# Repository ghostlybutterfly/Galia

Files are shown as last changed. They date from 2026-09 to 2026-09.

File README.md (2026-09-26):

# Galia
Modular split ergonomic keyboard system with each half consisting of a central motherboard and a hot-swappable key cluster daughterboard to allow for maximum flexibility.

### Motherboard
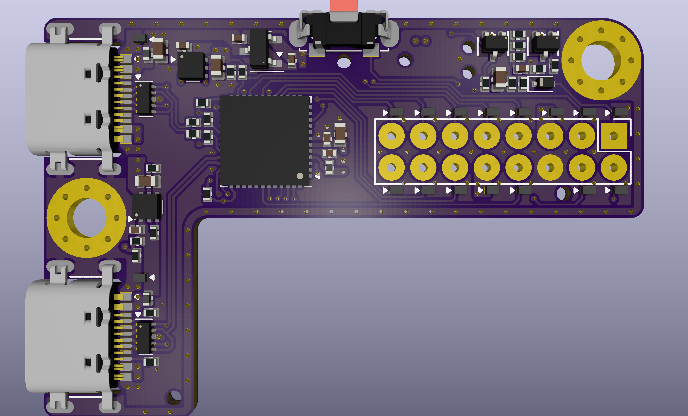
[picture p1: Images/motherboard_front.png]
Motherboard_Front

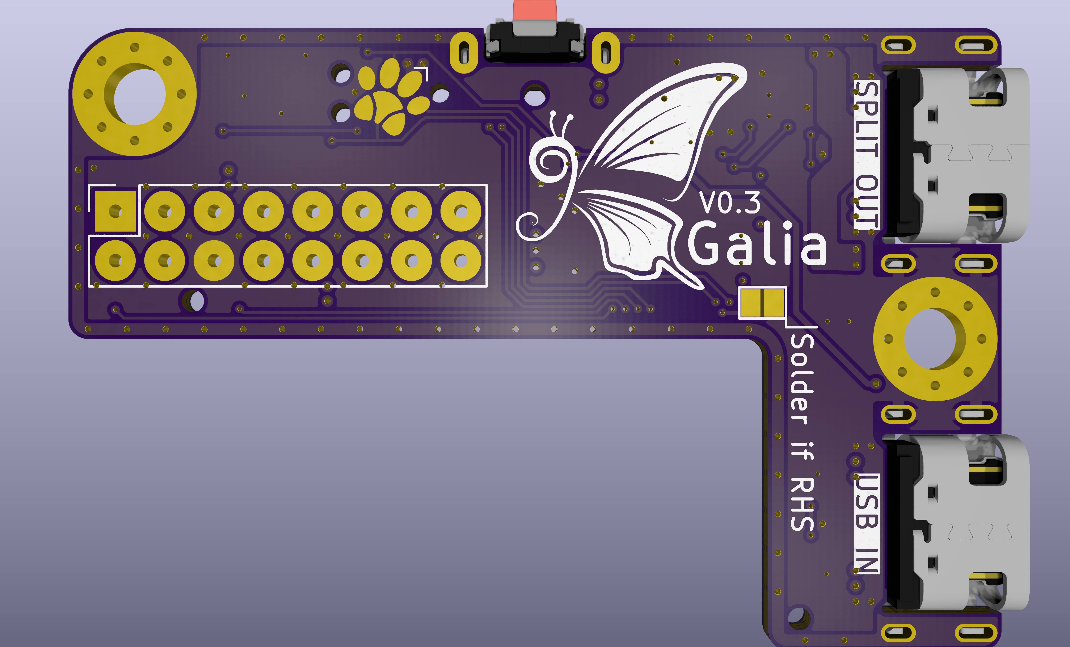
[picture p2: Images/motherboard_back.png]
Motherboard_Back

- Current version: V0.2.
- Schematic [here](https://kicanvas.org/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). 
- Board layout [here](https://kicanvas.org/?repo=https%3A%2F%2Fgithub.com%2Fghostlybutterfly%2FGalia%2Ftree%2FV0_dev%2FMotherboard).
### Daughterboard (Cantaloupe)
Current version: N/A (wip).

## Disclaimer
This keyboard is licensed under [CERN-OHL-S-2.0](https://cern-ohl.web.cern.ch/) and is compatible with both [QMK Firmware](https://qmk.fm/) and [ZMK Firmware](https://zmk.dev).

## Key Features
### Motherboard
* Fully reversible, compact (32.0x48.0mm), and designed to fit onto the top inner corner of a split keyboard.
* On-board STM32G0B1CCU7 processor.
* ESD-protected USB-C input port and USB-C split comms ports with ideal diode configuration for reverse current protection on VBUS input.
* Connects to daughterboard through fully ESD-protected 2.54mm pitch 02x08 pogo header in [VIK](https://github.com/sadekbaroudi/vik) breakout layout with three additional GPIO and reset button pin.
* 4-layer (signal/ground/power/signal) PCB, guard ring around PCB, and star ground connection point in between USB port shields to reduce EMI.
* VBUS input rail limited to ~500mA and 5V output rail limited to ~188mA through the use of TPS2553-1 current limiting switches with reverse voltage protection. VBUS requires power cycling to restart the device upon overcurrent, +5V can be power-cycled through firmware with EN pin controlled through firmware to reduce RGB LED quiescent current draw.
* 2x05 1.27mm Samtec IDC SWD header for debugging purposes or [Paw-Connect](https://github.com/LeoDJ/Paw-Connect) TC-2030NL header - both fit in the same space and are effectively interchangeable
* On-board button[Acheron](https://acheronproject.com/reset_article_1/reset_article_1/#52-substituting-the-jfet) single-button reset circuit.
* JLC basic assembly compatible as long as USB ports are not soldered on.

### Daughterboard (TBC)
* Matrix scan planned to be implemented through 74HC595 SIPO shift registers for low power draw and compatibility with ZMK interrupt functionality.
* Also compatible with charlieplex, duplex, and standard matrix layouts.
* WS2812 and AP102 (QMK only) LED support.
* Additional [VIK](https://github.com/sadekbaroudi/vik) header support if desired.
* USART1, USART3, and reset circuit pins routed to pogo pin header to allow for relocation of split comms receptacle and reset button on daughterboard.

## Pogo header pinout
| Function/description | Pin name | Row 1 | Row 2 | Pin name | Function/description |
| --- | --- | ----- | ----- | --- | --- |
| Active high, hold for 1.6s for DFU | N/A | RST | GPIO5 | B8 | SPI2 SCK/TIM4 CH3/I2C1 SCL |
| USART1 TX/SPI2 MISO/I2C1 SCL/TIM1 CH3 | B6 | GPIO3 | GPIO4 | B7 | USART1 RX/SPI2 MOSI/TIM4 CH2/I2C1 SDA |
| 200mA max draw across system | N/A | 3V3 | GND | N/A | N/A |
| I2C2 SDA | B4 | SDA | SCL | B3 | I2C2 SCL |
| SPI2 MOSI/TIM2 CH4 | B11 | RGB | 5V | N/A | 188mA max draw by daughterboard |
| USART3 TX/SPI2 MISO/ACD IN10 | B2 | GPIO1 | MOSI  | A7 | SPI1 MOSI |
| USART3 RX/TIM3 CH3/TIM1 CH2N/ADC IN8  | B0 | GPIO2 | CS | A4 | SPI1 NSS |
| SPI1 MISO | A6 | MISO  | SCK | A5 | SPI1 SCK |

## VIK keyboard certification card
| Category | Classification | Response |
| ---  | --- | --- |
| FPC connector | Required | 2.54mm pogo header |
| Breakout pins | Recommended | :heavy_check_mark: |
| Supplies: SPI | Strongly recommended | :heavy_check_mark: |
| Supplies: I2C | Strongly recommended | :heavy_check_mark: |
| I2C on main PCB | Discouraged | :x: |
| I2C pull ups | Informative | :x: |
| Supplies: RGB | Strongly recommended | :heavy_check_mark: |
| Supplies: Extra GPIO 1 | Required | Analog/Digital |
| Supplies: Extra GPIO 2 | Required | Analog/Digital |

## Changelog
* 2026/09/26: V0.3 motherboard update complete. Reduced size again, rerouted board and changed shape slightly. Removed one mounting hole and centred the other between the USB ports. Changed input fuse and external +5V output to TPS2553-1 latching power switch with reverse voltage/current protection. Removed AO3401 and LMV321 discrete reverse current protection at VBUS input. Reduced size of VBUS and VSPLIT ferrite bead and transistors in the Acheron reset circuit. Made Acheron reset circuit reach DFU faster. 
* 2026/09/21: V0.2 motherboard update complete. Significantly decreased size. GPIO3, GPIO4 and GPIO5 pins changed. Increased size of pogo pin header pads. Removed extra IO header. Replaced 2x03 2.54mm programming header and TC2030-NL with 2x05 1.27mm Samtec IDC header. Replaced reset switch with smaller Alps SKSNLP mid-mount switch. Added layer marker. Changed repository file structure.
* 2026/09/17: Fixed gap in guard rail.
* 2026/09/16: V0.1 motherboard initial commit.

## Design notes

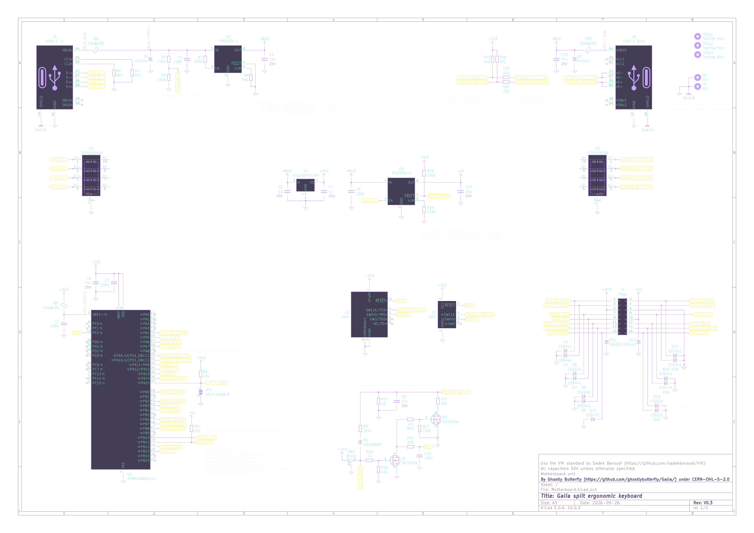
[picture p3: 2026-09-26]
Images/motherboard_schematic.png

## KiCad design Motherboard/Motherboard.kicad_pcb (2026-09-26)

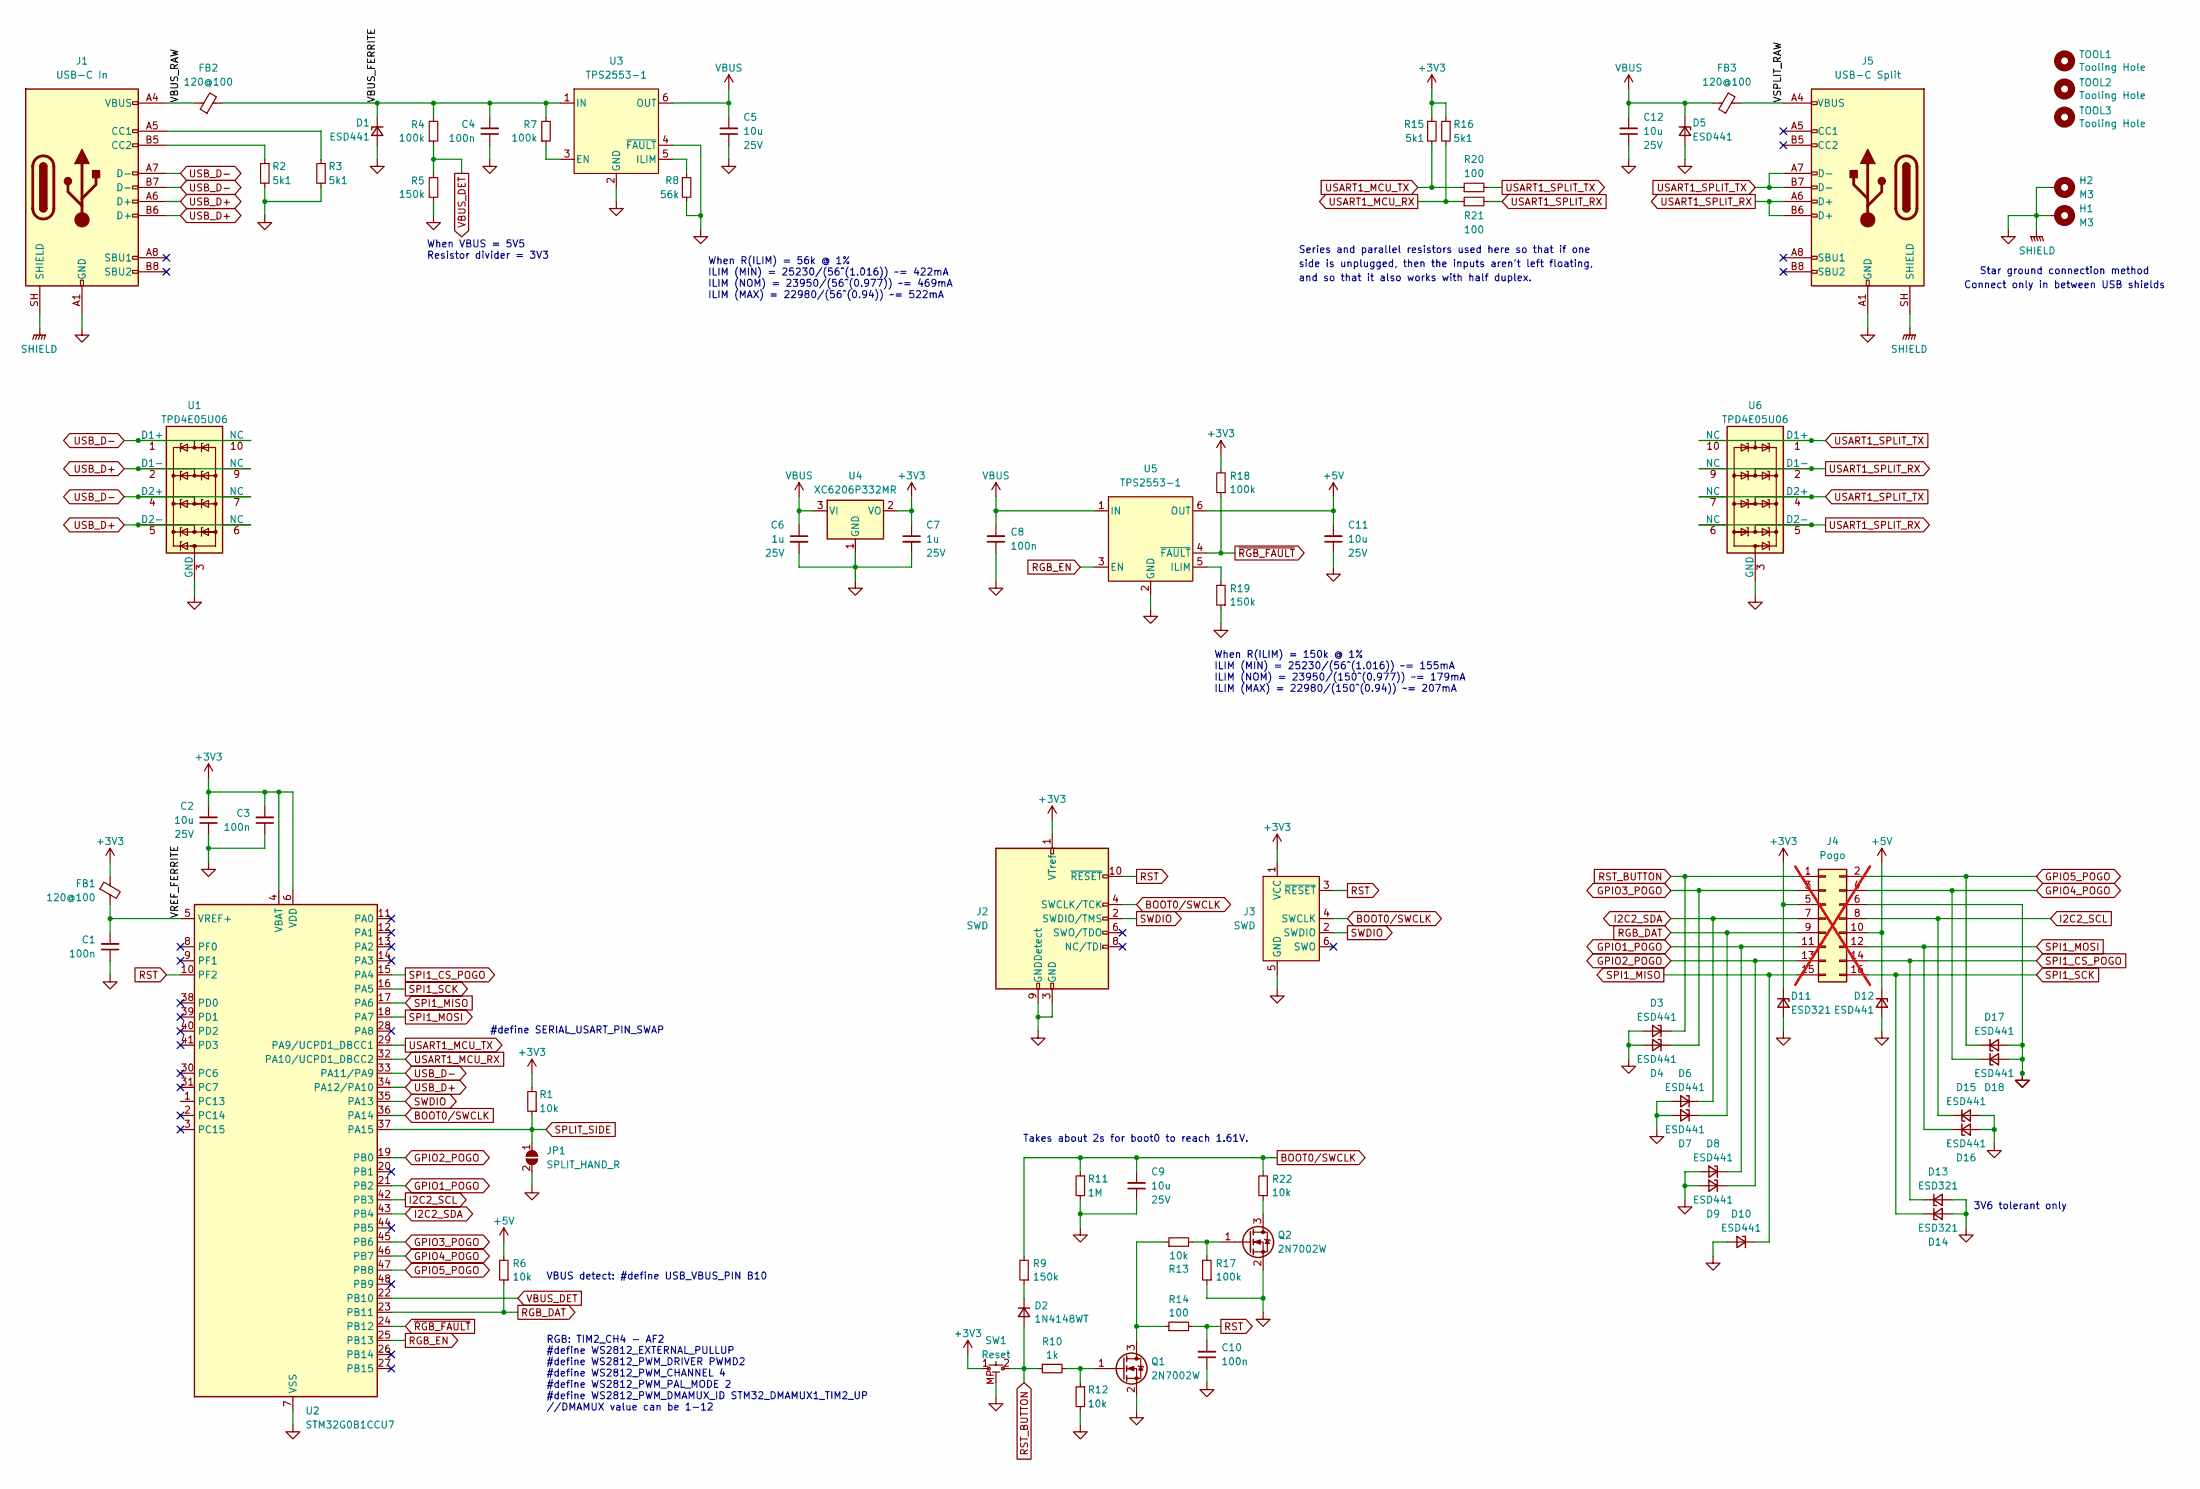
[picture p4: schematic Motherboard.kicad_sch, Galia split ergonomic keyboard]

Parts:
C1, C3, C4, C8, C10: 100n; C_0402_1005Metric; Rating 50V; MPN CL05B104KB54PNC; LCSC C307331
C2, C5, C9, C11, C12: 10u; C_0603_1608Metric; Rating 25V; MPN CL10A106MA8NRNC; LCSC C96446
C6, C7: 1u; C_0402_1005Metric; Rating 25V; MPN CL05A105KA5NQNC; LCSC C52923
D1, D3, D4, D5, D6, D7, D8, D9, D10, D12, D15, D16, D17, D18: ESD441; X1SON_0.6x1mm_P0.65mm_Texas_DPY0002A; MPN ESD441DPYR; LCSC C53161160
D2: 1N4148WT; D_SOD-523; MPN 1N4148WT; LCSC C7420320
D11, D13, D14: ESD321; X1SON_0.6x1mm_P0.65mm_Texas_DPY0002A; MPN ESD321DPYR; LCSC C2868952
FB1, FB2, FB3: 120@100; L_0402_1005Metric; MPN MPZ1005S121ET000; LCSC C275477
H1, H2: M3; MountingHole_3.2mm_M3_Pad_Via; MPN N/A; LCSC N/A
J1: USB-C In; USB_C_Receptacle_Molex_2169900001; MPN GT-USB-7014D; LCSC C2843969
J2: SWD; PinHeader_2x05_P1.27mm_Vertical_Samtec-FTSH-105-01-L-D-K; MPN FTSH-105-01-L-D-K; LCSC N/A
J3: SWD; Paw-Connect_RevB_TC2030-IDC-NL_2x03_P1.27mm_Vertical
J4: Pogo; PinHeader_2x08_2.54mm_MillMax_PogoTarget_419-10-216-00-0010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; MPN 419-10-214-00-001000; LCSC N/A; not fitted
J5: USB-C Split; USB_C_Receptacle_Molex_2169900001; MPN GT-USB-7014D; LCSC C2843969
JP1: SPLIT_HAND_R; SolderJumper-2_P1.2mm_Open_Pad1.0x1.4mm; MPN N/A; LCSC N/A
Q1, Q2: 2N7002W; SOT-323_SC-70-3; MPN 2N7002W; LCSC C7420322
R1, R6, R12, R13, R22: 10k; R_0402_1005Metric; MPN 0402WGF1002TCE; LCSC C25744
R2, R3, R15, R16: 5k1; R_0402_1005Metric; MPN 0402WGF5101TCE; LCSC C25905
R4, R7, R17, R18: 100k; R_0402_1005Metric; MPN 0402WGF1003TCE; LCSC C25741
R5, R9, R19: 150k; R_0402_1005Metric; MPN 0402WGF1503TCE; LCSC C25755
R8: 56k; R_0402_1005Metric; MPN 0402WGF5602TCE; LCSC C25796
R10: 1k; R_0402_1005Metric; MPN 0402WGF1001TCE; LCSC C11702
R11: 1M; R_0402_1005Metric; MPN 0402WGF1004TCE; LCSC C26083
R14, R20, R21: 100; R_0402_1005Metric; MPN 0402WGF1000TCE; LCSC C25076
SW1: Reset; SW_Alps_SKSNLM_SKSNLP; MPN SKSNLPE010; LCSC C53113391
TOOL1, TOOL2, TOOL3: Tooling Hole; MountingHole_JLC-Tooling; MPN N/A; LCSC N/A
U1, U6: TPD4E05U06; USON-10_2.5x1.0mm_P0.5mm; MPN TPD4E05U06QDQARQ1; LCSC C81353
U2: STM32G0B1CCU7; QFN-48-1EP_7x7mm_P0.5mm_EP5.6x5.6mm; MPN STM32G0B1CCU7; LCSC C29759424
U3, U5: TPS2553-1; WSON-6-1EP_2x2mm_P0.65mm_EP1x1.6mm
U4: XC6206P332MR; SOT-23-3; MPN XC6206P332MR-G; LCSC C5446

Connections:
+3V3: C2.2, C3.2, C7.1, D11.1 (K), FB1.1, J2.1 (VTref), J3.1 (VCC), J4.5, R1.2, R15.1, R16.1, R18.2, SW1.1 (A), U2.4 (VBAT), U2.6 (VDD), U4.2 (VO)
+5V: C11.2, D12.1 (K), J4.10, R6.2, U5.6 (OUT)
/VBUS_FERRITE: C4.2, D1.1 (K), FB2.2, R4.2, R7.2, U3.1 (IN)
/VBUS_RAW: FB2.1, J1.A4 (VBUS), J1.A9 (VBUS), J1.B4 (VBUS), J1.B9 (VBUS)
/VREF_FERRITE: C1.2, FB1.2, U2.5 (VREF+)
/VSPLIT_RAW: FB3.2, J5.A4 (VBUS), J5.A9 (VBUS), J5.B4 (VBUS), J5.B9 (VBUS)
BOOT0/SWCLK: C9.2, J2.4 (SWCLK/TCK), J3.4 (SWCLK), R9.2, R11.1, R22.2, U2.36 (PA14)
GND: C1.1, C2.1, C3.1, C4.1, C5.1, C6.2, C7.2, C8.1, C9.1, C10.1, C11.1, C12.1, D1.2 (A), D3.2 (A), D4.2 (A), D5.2 (A), D6.2 (A), D7.2 (A), D8.2 (A), D9.2 (A), D10.2 (A), D11.2 (A), D12.2 (A), D13.2 (A), D14.2 (A), D15.2 (A), D16.2 (A), D17.2 (A), D18.2 (A), H1.1 (1_1), H2.1 (1_1), J1.A1 (GND), J1.A12 (GND), J1.B1 (GND), J1.B12 (GND), J1.SH (SHIELD), J2.3 (GND), J2.5 (GND), J2.9 (GNDDetect), J3.5 (GND), J4.6, J5.A1 (GND), J5.A12 (GND), J5.B1 (GND), J5.B12 (GND), J5.SH (SHIELD), JP1.2 (B), Q1.2 (S), Q2.2 (S), R2.2, R3.2, R5.1, R8.2, R11.2, R12.2, R17.1, R19.1, SW1.MP (A), U1.3 (GND), U1.8 (GND), U2.7 (VSS), U2.49 (VSS), U3.2 (GND), U3.4 (~FAULT), U3.7 (EP), U4.1 (GND), U5.2 (GND), U5.7 (EP), U6.3 (GND), U6.8 (GND)
GPIO1_POGO: D8.1 (K), J4.11, U2.21 (PB2)
GPIO2_POGO: D9.1 (K), J4.13, U2.19 (PB0)
GPIO3_POGO: D4.1 (K), J4.3, U2.45 (PB6)
GPIO4_POGO: D18.1 (K), J4.4, U2.46 (PB7)
GPIO5_POGO: D17.1 (K), J4.2, U2.47 (PB8)
I2C2_SCL: D15.1 (K), J4.8, U2.42 (PB3)
I2C2_SDA: D6.1 (K), J4.7, U2.43 (PB4)
unnamed: D2.1 (K), R9.1
unnamed: J1.A5 (CC1), R3.1
unnamed: J1.B5 (CC2), R2.1
unnamed: Q1.3 (D), R13.1, R14.1
unnamed: Q1.1 (G), R10.2, R12.1
unnamed: Q2.3 (D), R22.1
unnamed: Q2.1 (G), R13.2, R17.2
unnamed: R7.1, U3.3 (EN)
unnamed: R8.1, U3.5 (ILIM)
unnamed: R19.2, U5.5 (ILIM)
RGB_DAT: D7.1 (K), J4.9, R6.1, U2.23 (PB11)
RGB_EN: U2.25 (PB13), U5.3 (EN)
RST: C10.2, J2.10 (~RESET), J3.3 (~RESET), R14.2, U2.10 (PF2)
RST_BUTTON: D2.2 (A), D3.1 (K), J4.1, R10.1, SW1.2 (B)
SPI1_CS_POGO: D13.1 (K), J4.14, U2.15 (PA4)
SPI1_MISO: D10.1 (K), J4.15, U2.17 (PA6)
SPI1_MOSI: D16.1 (K), J4.12, U2.18 (PA7)
SPI1_SCK: D14.1 (K), J4.16, U2.16 (PA5)
SPLIT_SIDE: JP1.1 (A), R1.1, U2.37 (PA15)
SWDIO: J2.2 (SWDIO/TMS), J3.2 (SWDIO), U2.35 (PA13)
USART1_MCU_RX: R16.2, R21.1, U2.32 (PA10/UCPD1_DBCC2)
USART1_MCU_TX: R15.2, R20.1, U2.29 (PA9/UCPD1_DBCC1)
USART1_SPLIT_RX: J5.A6 (D+), J5.B6 (D+), R21.2, U6.2 (D1-), U6.5 (D2-), U6.6 (NC), U6.9 (NC)
USART1_SPLIT_TX: J5.A7 (D-), J5.B7 (D-), R20.2, U6.1 (D1+), U6.4 (D2+), U6.7 (NC), U6.10 (NC)
USB_D+: J1.A6 (D+), J1.B6 (D+), U1.2 (D1-), U1.5 (D2-), U1.6 (NC), U1.9 (NC), U2.34 (PA12/PA10)
USB_D-: J1.A7 (D-), J1.B7 (D-), U1.1 (D1+), U1.4 (D2+), U1.7 (NC), U1.10 (NC), U2.33 (PA11/PA9)
VBUS: C5.2, C6.1, C8.2, C12.2, D5.1 (K), FB3.1, U3.6 (OUT), U4.3 (VI), U5.1 (IN)
VBUS_DET: R4.1, R5.2, U2.22 (PB10)
~RGB_FAULT: R18.1, U2.24 (PB12), U5.4 (~FAULT)

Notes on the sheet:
3V6 tolerant only
#define WS2812_EXTERNAL_PULLUP #define WS2812_PWM_DRIVER PWMD2 #define WS2812_PWM_CHANNEL 4 #define WS2812_PWM_PAL_MODE 2 #define WS2812_PWM_DMAMUX_ID STM32_DMAMUX1_TIM2_UP //DMAMUX value can be 1-12
When R(ILIM) = 56k @ 1% ILIM (MIN) = 25230/(56^(1.016)) ~= 422mA ILIM (NOM) = 23950/(56^(0.977)) ~= 469mA ILIM (MAX) = 22980/(56^(0.94)) ~= 522mA
Takes about 2s for boot0 to reach 1.61V.
RGB: TIM2_CH4 - AF2
Series and parallel resistors used here so that if one
VBUS detect: #define USB_VBUS_PIN B10
side is unplugged, then the inputs aren't left floating,
and so that it also works with half duplex.
When VBUS = 5V5 Resistor divider = 3V3
Connect only in between USB shields
#define SERIAL_USART_PIN_SWAP
When R(ILIM) = 150k @ 1% ILIM (MIN) = 25230/(56^(1.016)) ~= 155mA ILIM (NOM) = 23950/(150^(0.977)) ~= 179mA ILIM (MAX) = 22980/(150^(0.94)) ~= 207mA
Star ground connection method

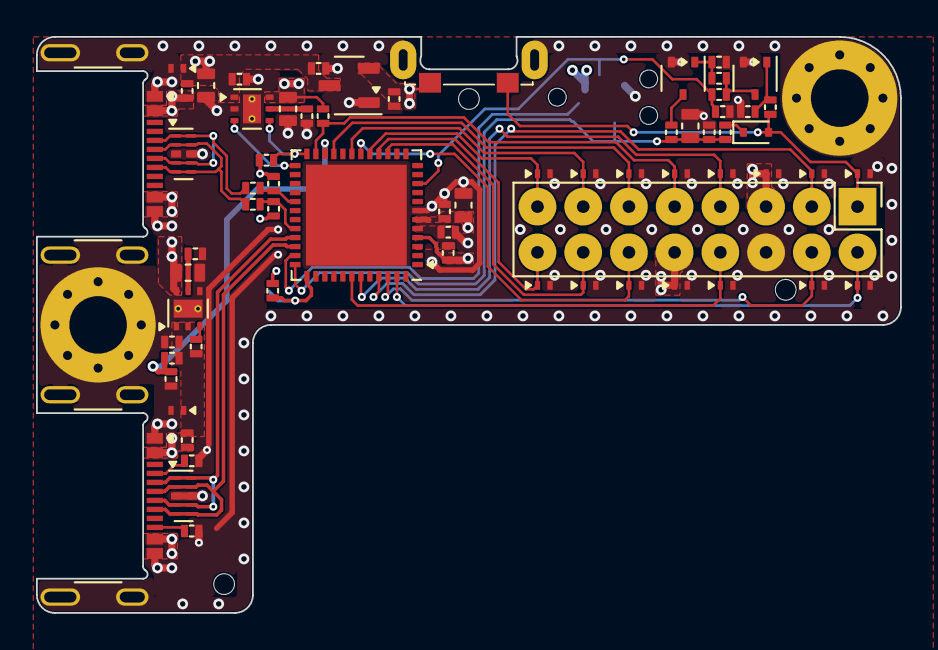
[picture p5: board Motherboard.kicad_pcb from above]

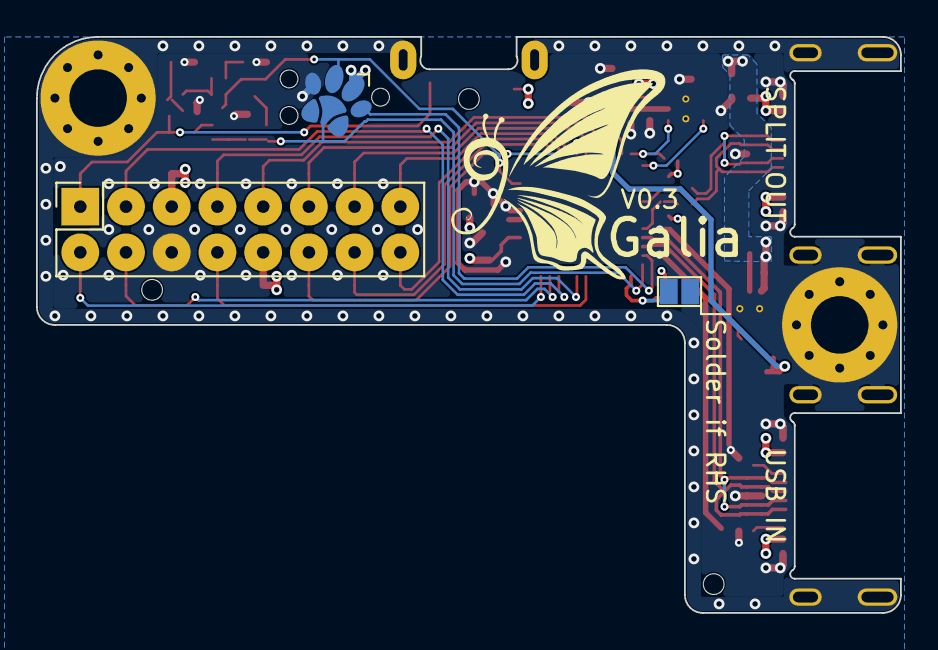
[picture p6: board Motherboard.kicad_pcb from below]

Board: 4 copper layers, 48.0 x 32.0 mm, 74 parts (3 on the bottom side), 44 nets.

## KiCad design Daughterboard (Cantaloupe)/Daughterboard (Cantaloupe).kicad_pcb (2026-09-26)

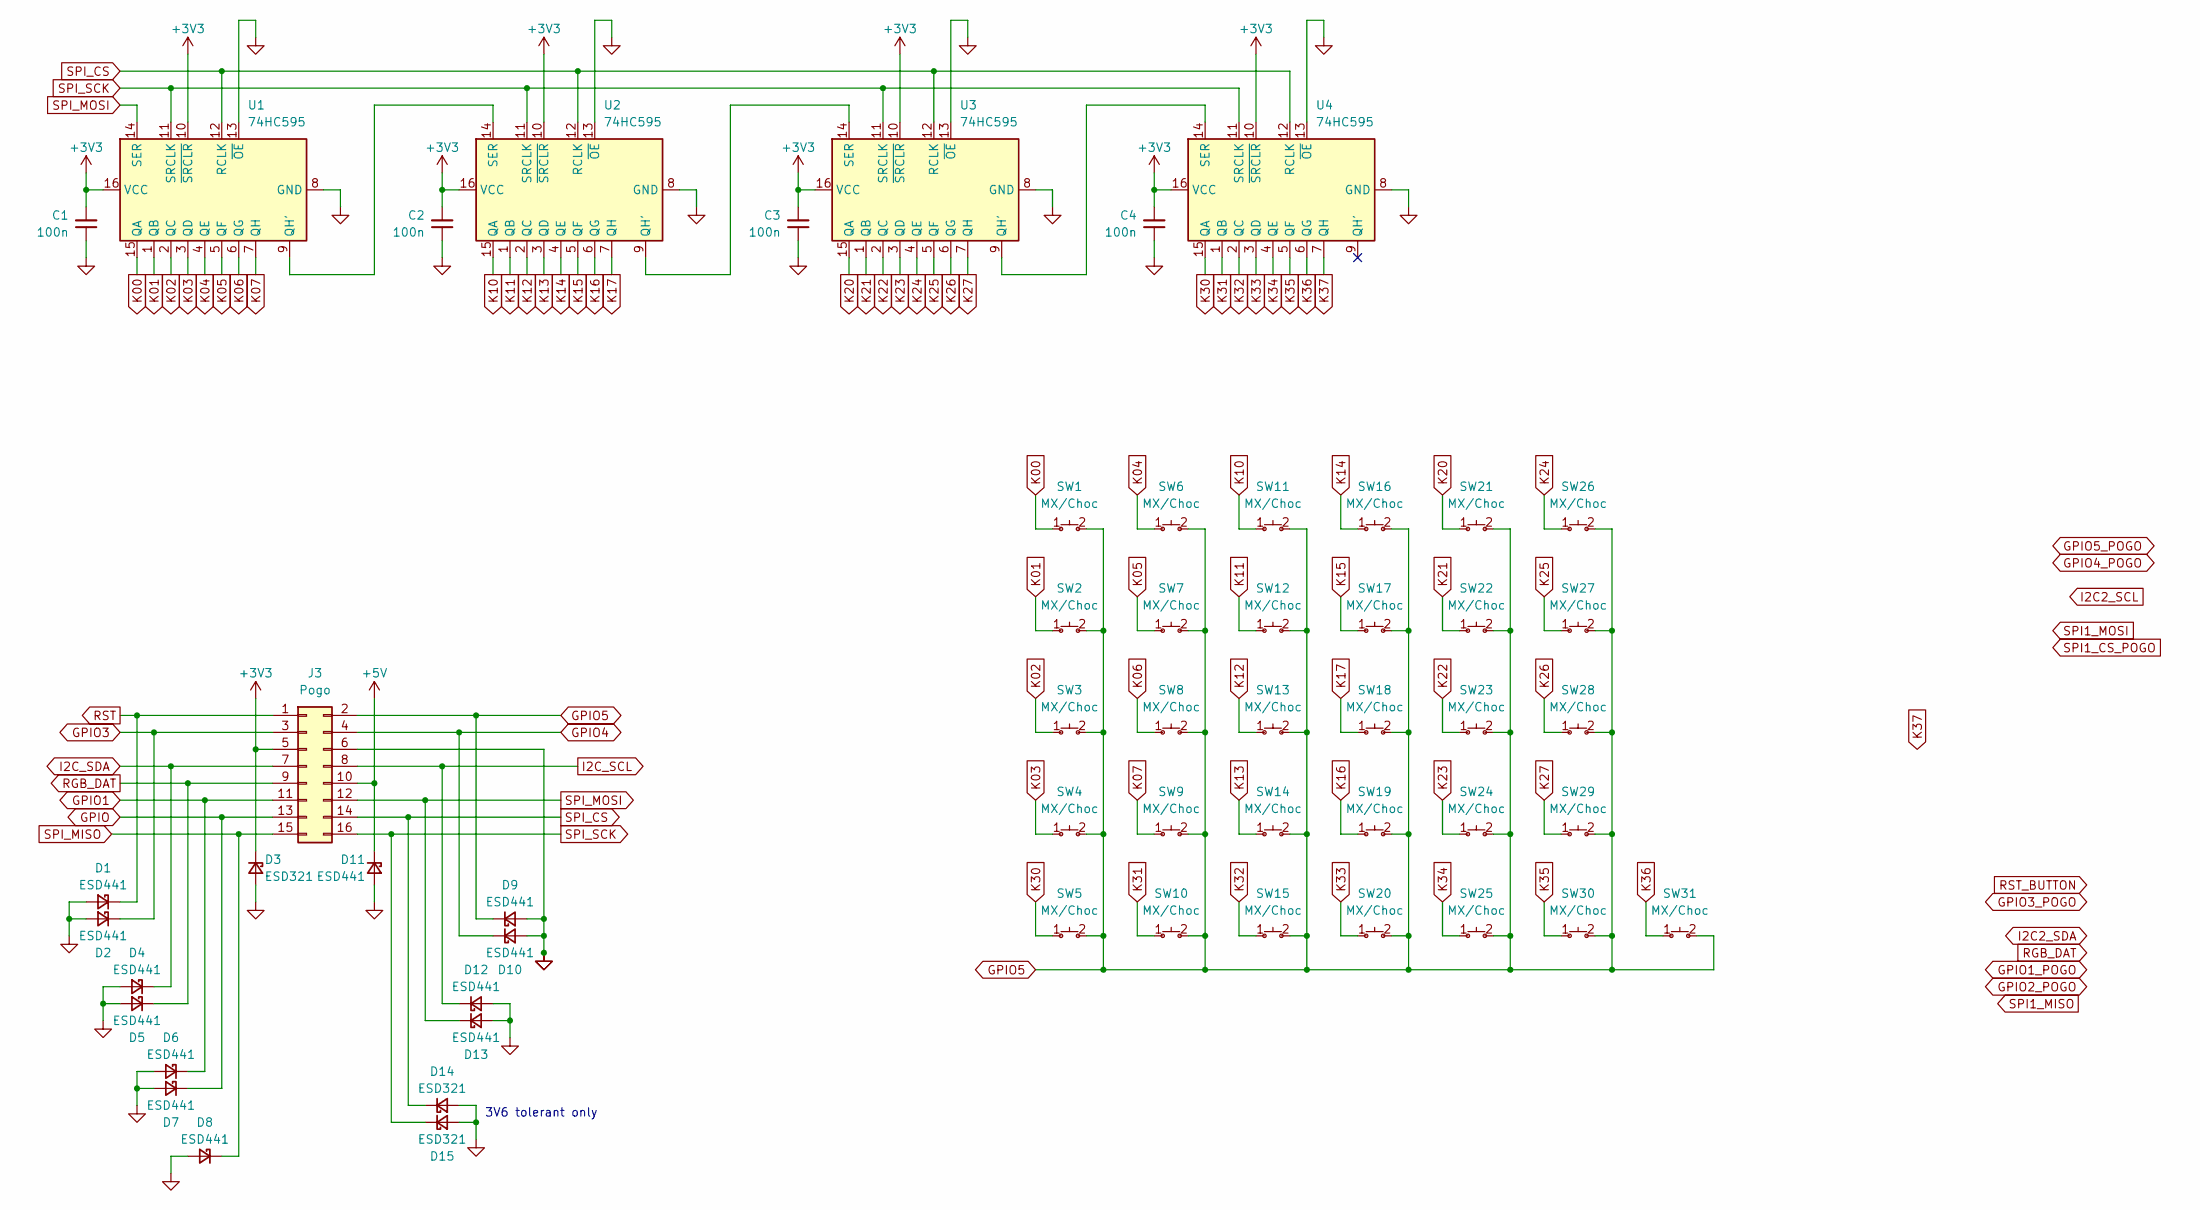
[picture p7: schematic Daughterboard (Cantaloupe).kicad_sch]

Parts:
C1, C2, C3, C4: 100n; C_0402_1005Metric; Voltage 50V; MPN CL05B104KB54PNC; LCSC C307331
D1, D2, D4, D5, D6, D7, D8, D9, D10, D11, D12, D13: ESD441; X1SON_0.6x1mm_P0.65mm_Texas_DPY0002A; MPN ESD441DPYR; LCSC C53161160
D3, D14, D15: ESD321; X1SON_0.6x1mm_P0.65mm_Texas_DPY0002A; MPN ESD321DPYR; LCSC C2868952
J3: Pogo; PinHeader_2x08_2.54mm_MillMax_PogoPin_823-22-016-10-002101_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; MPN 419-10-214-00-001000
SW1, SW2, SW3, SW4, SW5, SW6, SW7, SW8, SW9, SW10, SW11, SW12, SW13, SW14, SW15, SW16, SW17, SW18, SW19, SW20, SW21, SW22, SW23, SW24, SW25, SW26, SW27, SW28, SW29, SW30, SW31: MX/Choc; SW_MX-Choc_1U_Hotswap_Flippable
U1, U2, U3, U4: 74HC595; DHVQFN-16-1EP_2.5x3.5mm_P0.5mm_EP1x2mm; MPN 74HC595BQ,115; LCSC C730243

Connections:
+3V3: C1.2, C2.2, C3.2, C4.2, D3.1 (K), J3.5, U1.10 (~SRCLR), U1.16 (VCC), U2.10 (~SRCLR), U2.16 (VCC), U3.10 (~SRCLR), U3.16 (VCC), U4.10 (~SRCLR), U4.16 (VCC)
+5V: D11.1 (K), J3.10
GND: C1.1, C2.1, C3.1, C4.1, D1.2 (A), D2.2 (A), D3.2 (A), D4.2 (A), D5.2 (A), D6.2 (A), D7.2 (A), D8.2 (A), D9.2 (A), D10.2 (A), D11.2 (A), D12.2 (A), D13.2 (A), D14.2 (A), D15.2 (A), J3.6, U1.8 (GND), U1.13 (~OE), U1.17 (EP), U2.8 (GND), U2.13 (~OE), U2.17 (EP), U3.8 (GND), U3.13 (~OE), U3.17 (EP), U4.8 (GND), U4.13 (~OE), U4.17 (EP)
GPIO: D7.1 (K), J3.13
GPIO1: D6.1 (K), J3.11
GPIO3: D2.1 (K), J3.3
GPIO4: D10.1 (K), J3.4
GPIO5: D9.1 (K), J3.2, SW1.2 (B), SW2.2 (B), SW3.2 (B), SW4.2 (B), SW5.2 (B), SW6.2 (B), SW7.2 (B), SW8.2 (B), SW9.2 (B), SW10.2 (B), SW11.2 (B), SW12.2 (B), SW13.2 (B), SW14.2 (B), SW15.2 (B), SW16.2 (B), SW17.2 (B), SW18.2 (B), SW19.2 (B), SW20.2 (B), SW21.2 (B), SW22.2 (B), SW23.2 (B), SW24.2 (B), SW25.2 (B), SW26.2 (B), SW27.2 (B), SW28.2 (B), SW29.2 (B), SW30.2 (B), SW31.2 (B)
I2C_SCL: D12.1 (K), J3.8
I2C_SDA: D4.1 (K), J3.7
K00: SW1.1 (A), U1.15 (QA)
K01: SW2.1 (A), U1.1 (QB)
K02: SW3.1 (A), U1.2 (QC)
K03: SW4.1 (A), U1.3 (QD)
K04: SW6.1 (A), U1.4 (QE)
K05: SW7.1 (A), U1.5 (QF)
K06: SW8.1 (A), U1.6 (QG)
K07: SW9.1 (A), U1.7 (QH)
K10: SW11.1 (A), U2.15 (QA)
K11: SW12.1 (A), U2.1 (QB)
K12: SW13.1 (A), U2.2 (QC)
K13: SW14.1 (A), U2.3 (QD)
K14: SW16.1 (A), U2.4 (QE)
K15: SW17.1 (A), U2.5 (QF)
K16: SW19.1 (A), U2.6 (QG)
K17: SW18.1 (A), U2.7 (QH)
K20: SW21.1 (A), U3.15 (QA)
K21: SW22.1 (A), U3.1 (QB)
K22: SW23.1 (A), U3.2 (QC)
K23: SW24.1 (A), U3.3 (QD)
K24: SW26.1 (A), U3.4 (QE)
K25: SW27.1 (A), U3.5 (QF)
K26: SW28.1 (A), U3.6 (QG)
K27: SW29.1 (A), U3.7 (QH)
K30: SW5.1 (A), U4.15 (QA)
K31: SW10.1 (A), U4.1 (QB)
K32: SW15.1 (A), U4.2 (QC)
K33: SW20.1 (A), U4.3 (QD)
K34: SW25.1 (A), U4.4 (QE)
K35: SW30.1 (A), U4.5 (QF)
K36: SW31.1 (A), U4.6 (QG)
K37: U4.7 (QH)
unnamed: U1.9 (QH'), U2.14 (SER)
unnamed: U2.9 (QH'), U3.14 (SER)
unnamed: U3.9 (QH'), U4.14 (SER)
RGB_DAT: D5.1 (K), J3.9
RST: D1.1 (K), J3.1
SPI_CS: D14.1 (K), J3.14, U1.12 (RCLK), U2.12 (RCLK), U3.12 (RCLK), U4.12 (RCLK)
SPI_MISO: D8.1 (K), J3.15
SPI_MOSI: D13.1 (K), J3.12, U1.14 (SER)
SPI_SCK: D15.1 (K), J3.16, U1.11 (SRCLK), U2.11 (SRCLK), U3.11 (SRCLK), U4.11 (SRCLK)

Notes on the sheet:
3V6 tolerant only

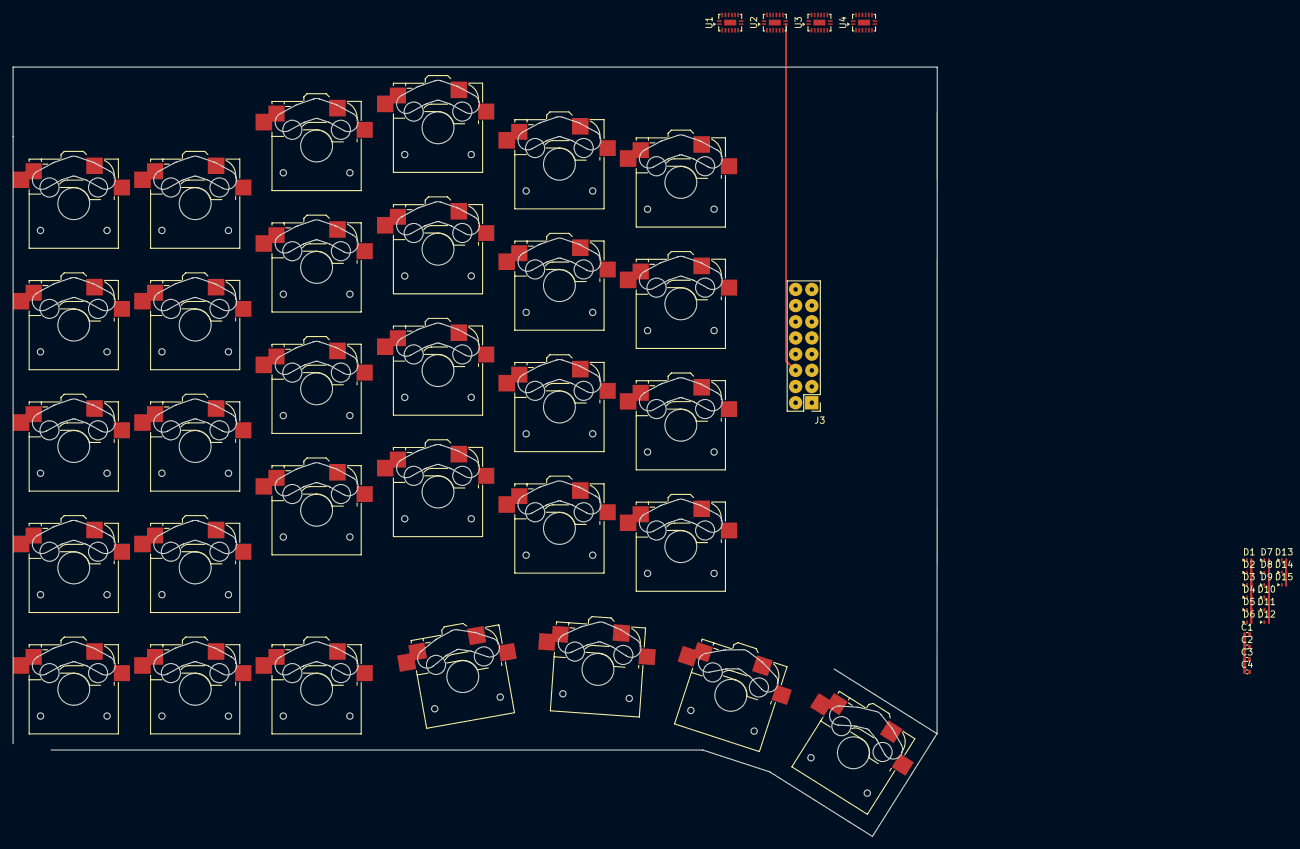
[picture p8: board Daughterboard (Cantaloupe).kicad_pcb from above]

Board: 2 copper layers, 55 parts (0 on the bottom side), 50 nets.

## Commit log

2026-09-17 2026/09/16 - V0.1 motherboard initial commit
    [motherboard.kicad_pcb, motherboard.kicad_sch]
2026-09-17 2026/09/17: Fixed gap in guard rail
    [motherboard.kicad_pcb]
2026-09-22 2026/09/21: V0.2 motherboard update complete
    Significantly decreased size. GPIO3, GPIO4 and GPIO5 pins changed. Increased size of pogo pin header pads. Removed extra IO header. Replaced 2x03 2.54mm programming header and TC2030-NL with 2x05 1.27mm Samtec IDC header. Replaced reset switch with smaller Alps SKSNLP mid-mount switch. Added layer marker. Changed repository file structure.
    [Motherboard.kicad_pcb, Motherboard.kicad_sch, motherboard.kicad_pcb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]
2026-09-26 2026/09/26: V0.3 motherboard update complete
    Reduced size again, rerouted board and changed shape slightly. Removed one mounting hole and centred the other between the USB ports. Changed input fuse and external +5V output to TPS2553-1 latching power switch with reverse voltage/current protection. Removed AO3401 and LMV321 discrete reverse current protection at VBUS input. Reduced size of VBUS and VSPLIT ferrite bead and transistors in the Acheron reset circuit. Made Acheron reset circuit reach DFU faster.
    [Daughterboard (Cantaloupe).kicad_pcb, Daughterboard (Cantaloupe).kicad_sch, Motherboard.kicad_pcb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]

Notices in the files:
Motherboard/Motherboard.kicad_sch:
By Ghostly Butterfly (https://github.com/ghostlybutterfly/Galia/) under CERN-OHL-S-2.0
